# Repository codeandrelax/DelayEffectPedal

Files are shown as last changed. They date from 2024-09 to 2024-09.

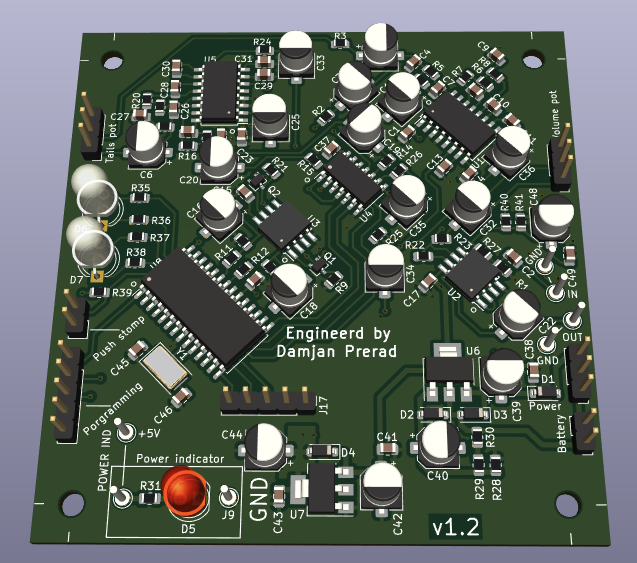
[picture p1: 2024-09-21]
PCB_render.png

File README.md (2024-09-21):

# The Time Manipulator

<p align="center">
  3D render
  Block diagram
</p>

This repository contains schematic, design files and firmware for digital delay guitar effect pedal based on PT2399.
Effect pedal was inspired by [_The Time Manipulator_](https://www.electrosmash.com/time-manipulator) effect pedal.

Electro Smash's pedal is built using popular Arduino ATMEGA328P-PU chip. 
Solution found in this repositroy doesn't use the same microcontroller. It uses PIC16F72.

Board is designed using surface mounted components (SMD).

Aditionaly, I have written on effect pedal design, it can be found in the repository [Analogna Efekt Pedala](./Analogna%20Efekt%20Pedala.pdf) (it's in Serbian)

## First version of the board

<table>
  <tr>
    <td></td>
    <td></td>
    <td></td>
  </tr>
  <tr>
    <td></td>
    <td></td>
    <td></td>
  </tr>
</table>

Firmware and PCB design of PT2399 IC based digital delay  effect guitar pedal

## Development diagram

DevelopmentDiagram

## Render images







## Block diagram



## Schematics
[Schematics](PT2399_DigitalEffectPedal.pdf) PDF can be found in the repository. 



## Layout

Board dimensions are 75 mm by 78 mm.
Board layout is done as 4 layer board.



### Front Cu layer:


### In1. Cu layer:


### In2. Cu layer:
This layer has two power planes. Bigger one is for 5V supply, and the smaller one is for 9V supply.


### Back Cu layer:


## Firmawrae

## Tools

Tool used for schematics drwaing and pcb layout is [KiCad](https://www.kicad.org/), version 7.0.7

Tools used to draw block image is [ExcaliDraw](https://excalidraw.com/).

## TO DO

- Encoder board

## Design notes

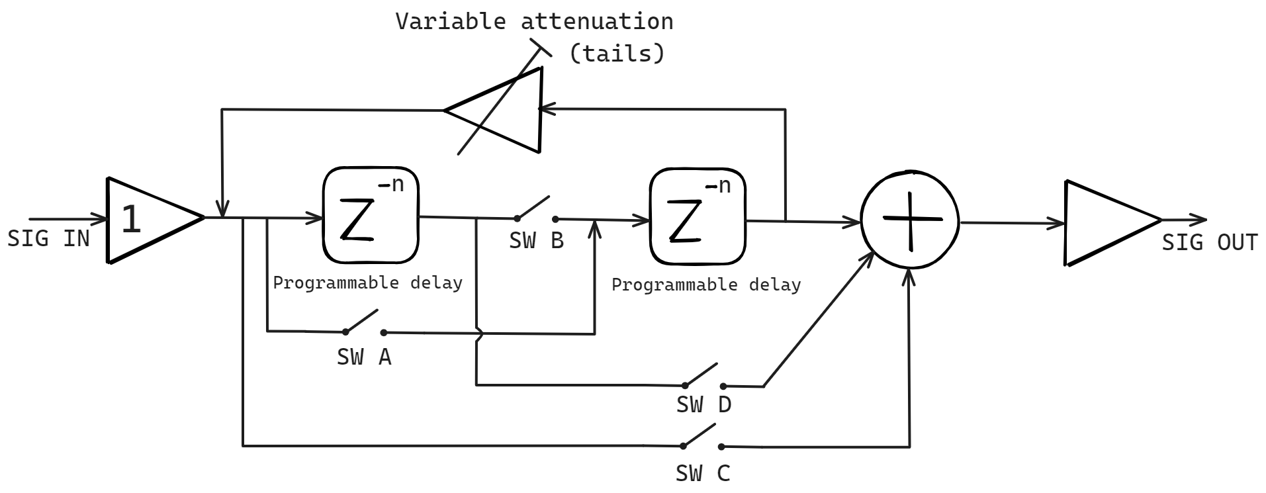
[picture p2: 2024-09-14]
TimeManipulator_blockDiagram.png

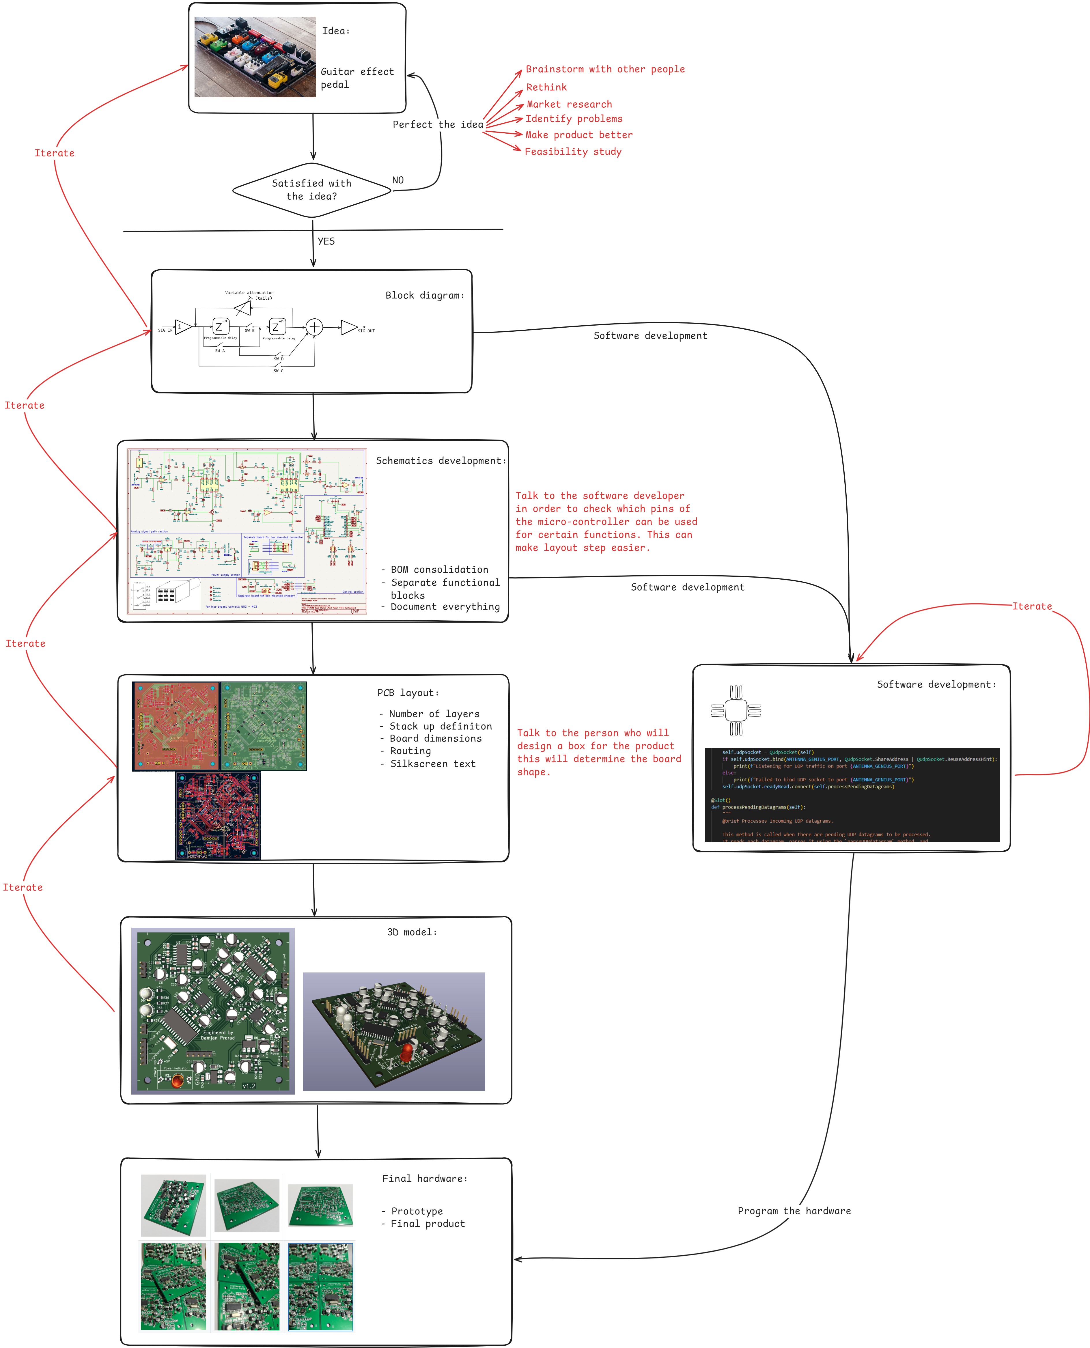
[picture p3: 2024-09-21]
DevelopmentDiagram.png

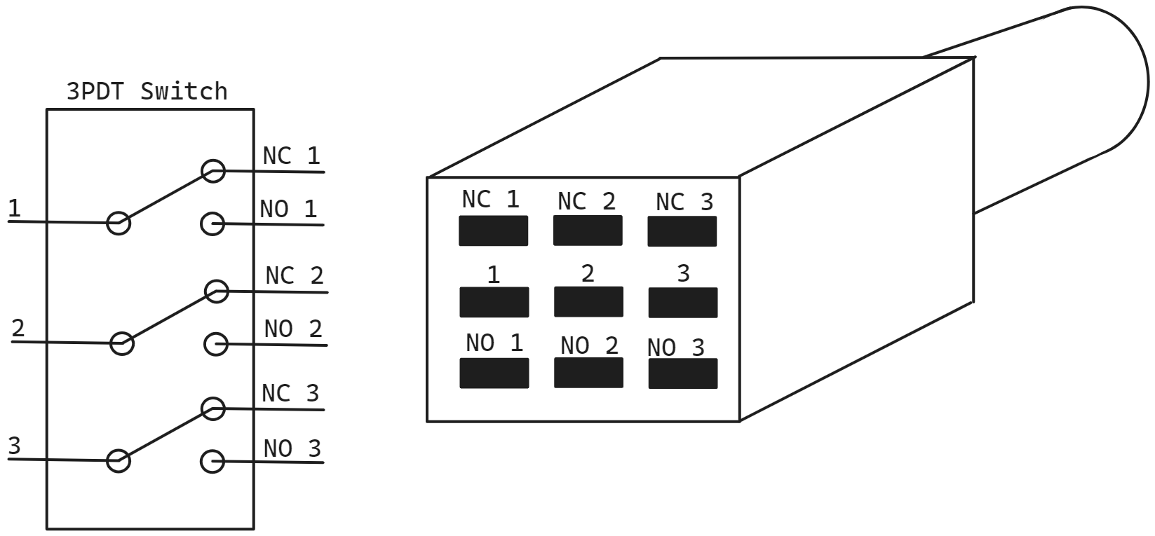
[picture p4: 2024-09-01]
3PDT_switch.png

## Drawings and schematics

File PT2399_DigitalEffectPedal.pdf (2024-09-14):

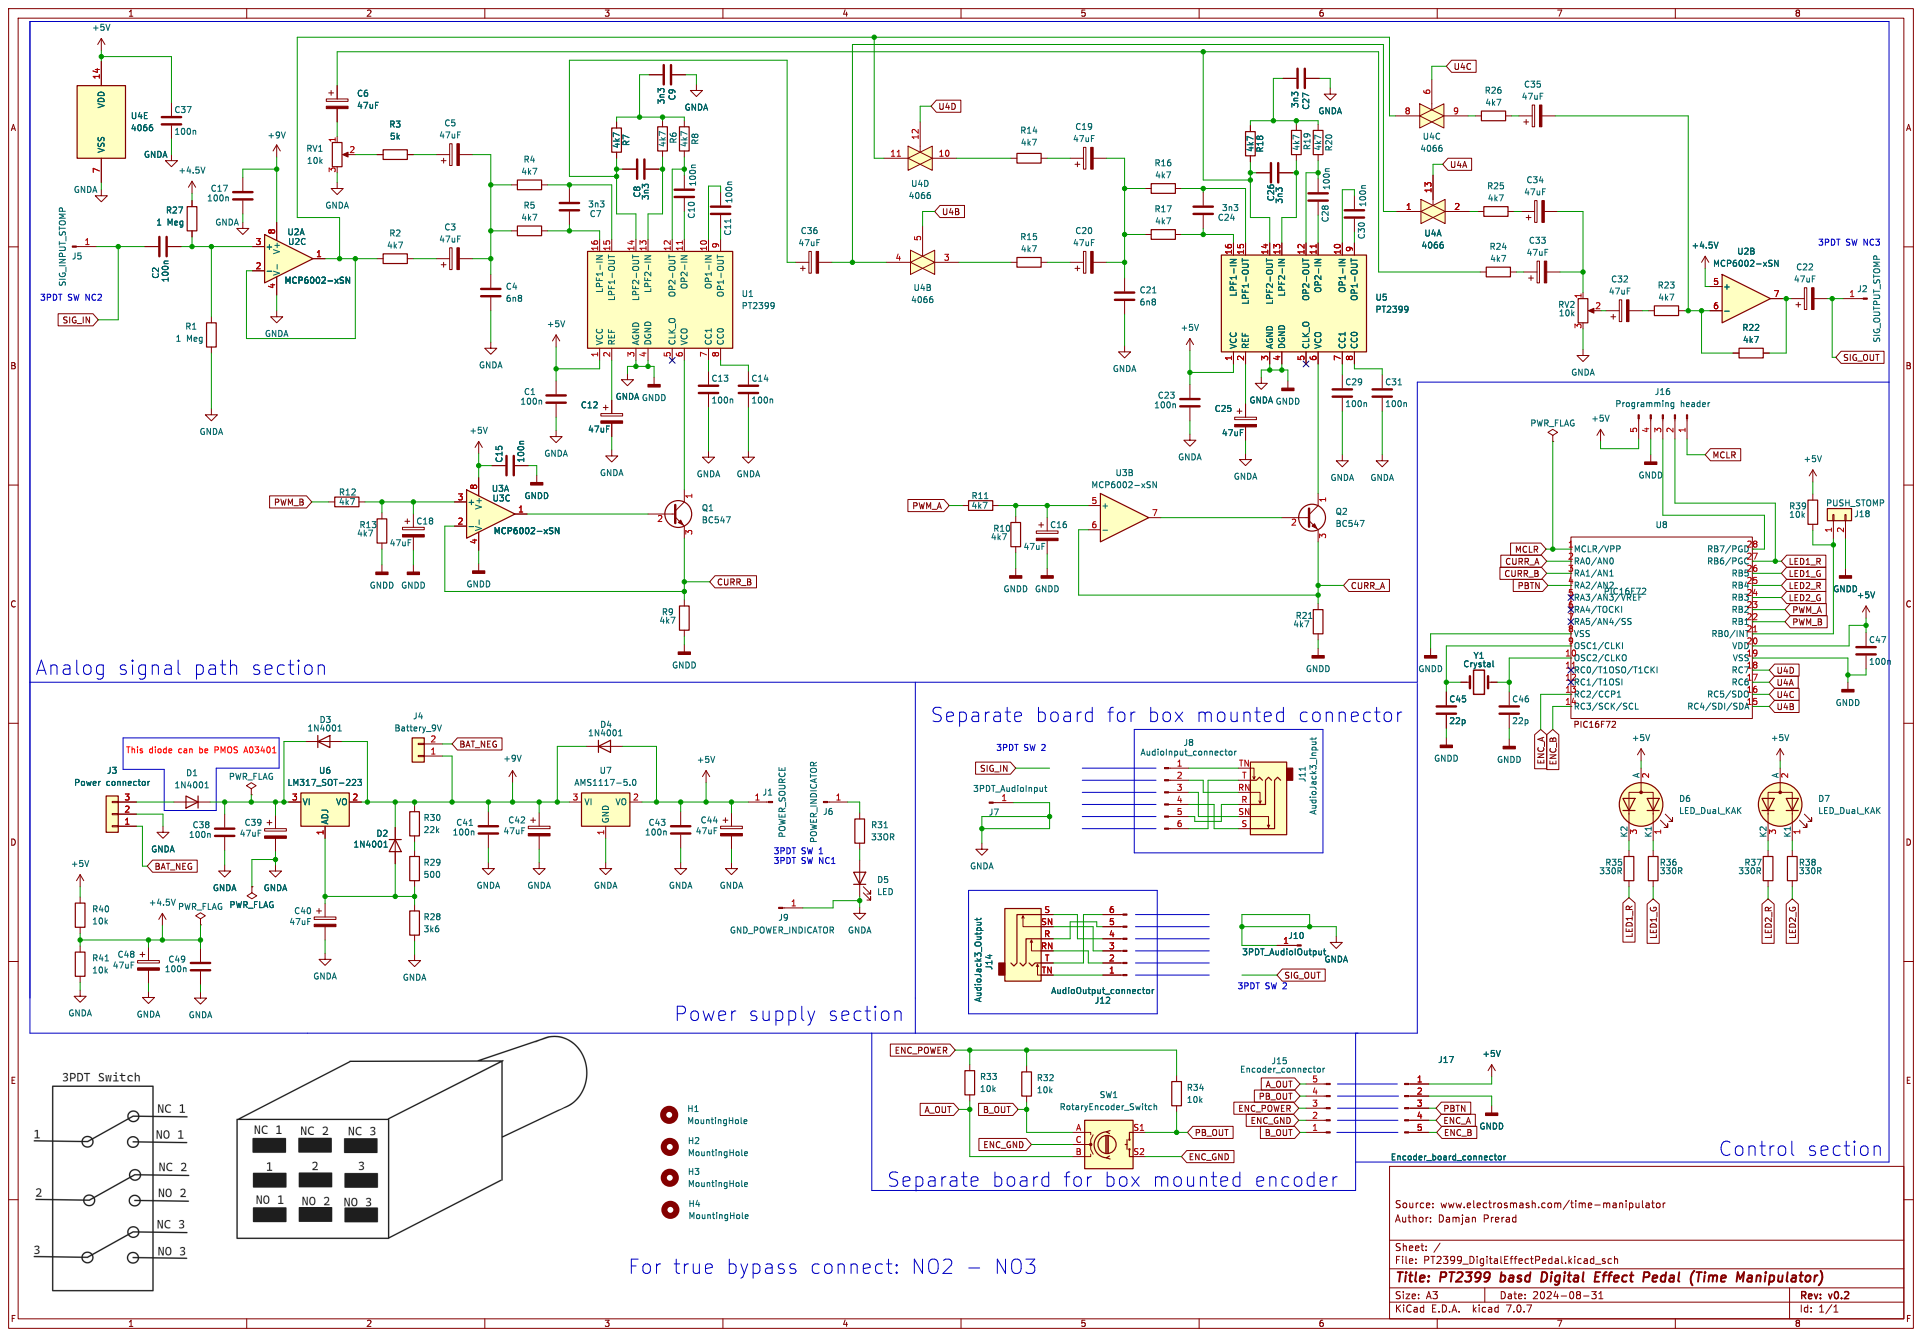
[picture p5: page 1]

1 OP1-IN 10 OP2-IN 11 OP2-OUT 12 LPF2-IN 13 LPF2-OUT 14 LPF1-OUT 15 LPF1-IN 16 REF

Analog signal path section

This diode can be PMOS A03401

3PDT SW NC1 Power supply section

Separate board for box mounted encoder

For true bypass connect: NO2 - NO3

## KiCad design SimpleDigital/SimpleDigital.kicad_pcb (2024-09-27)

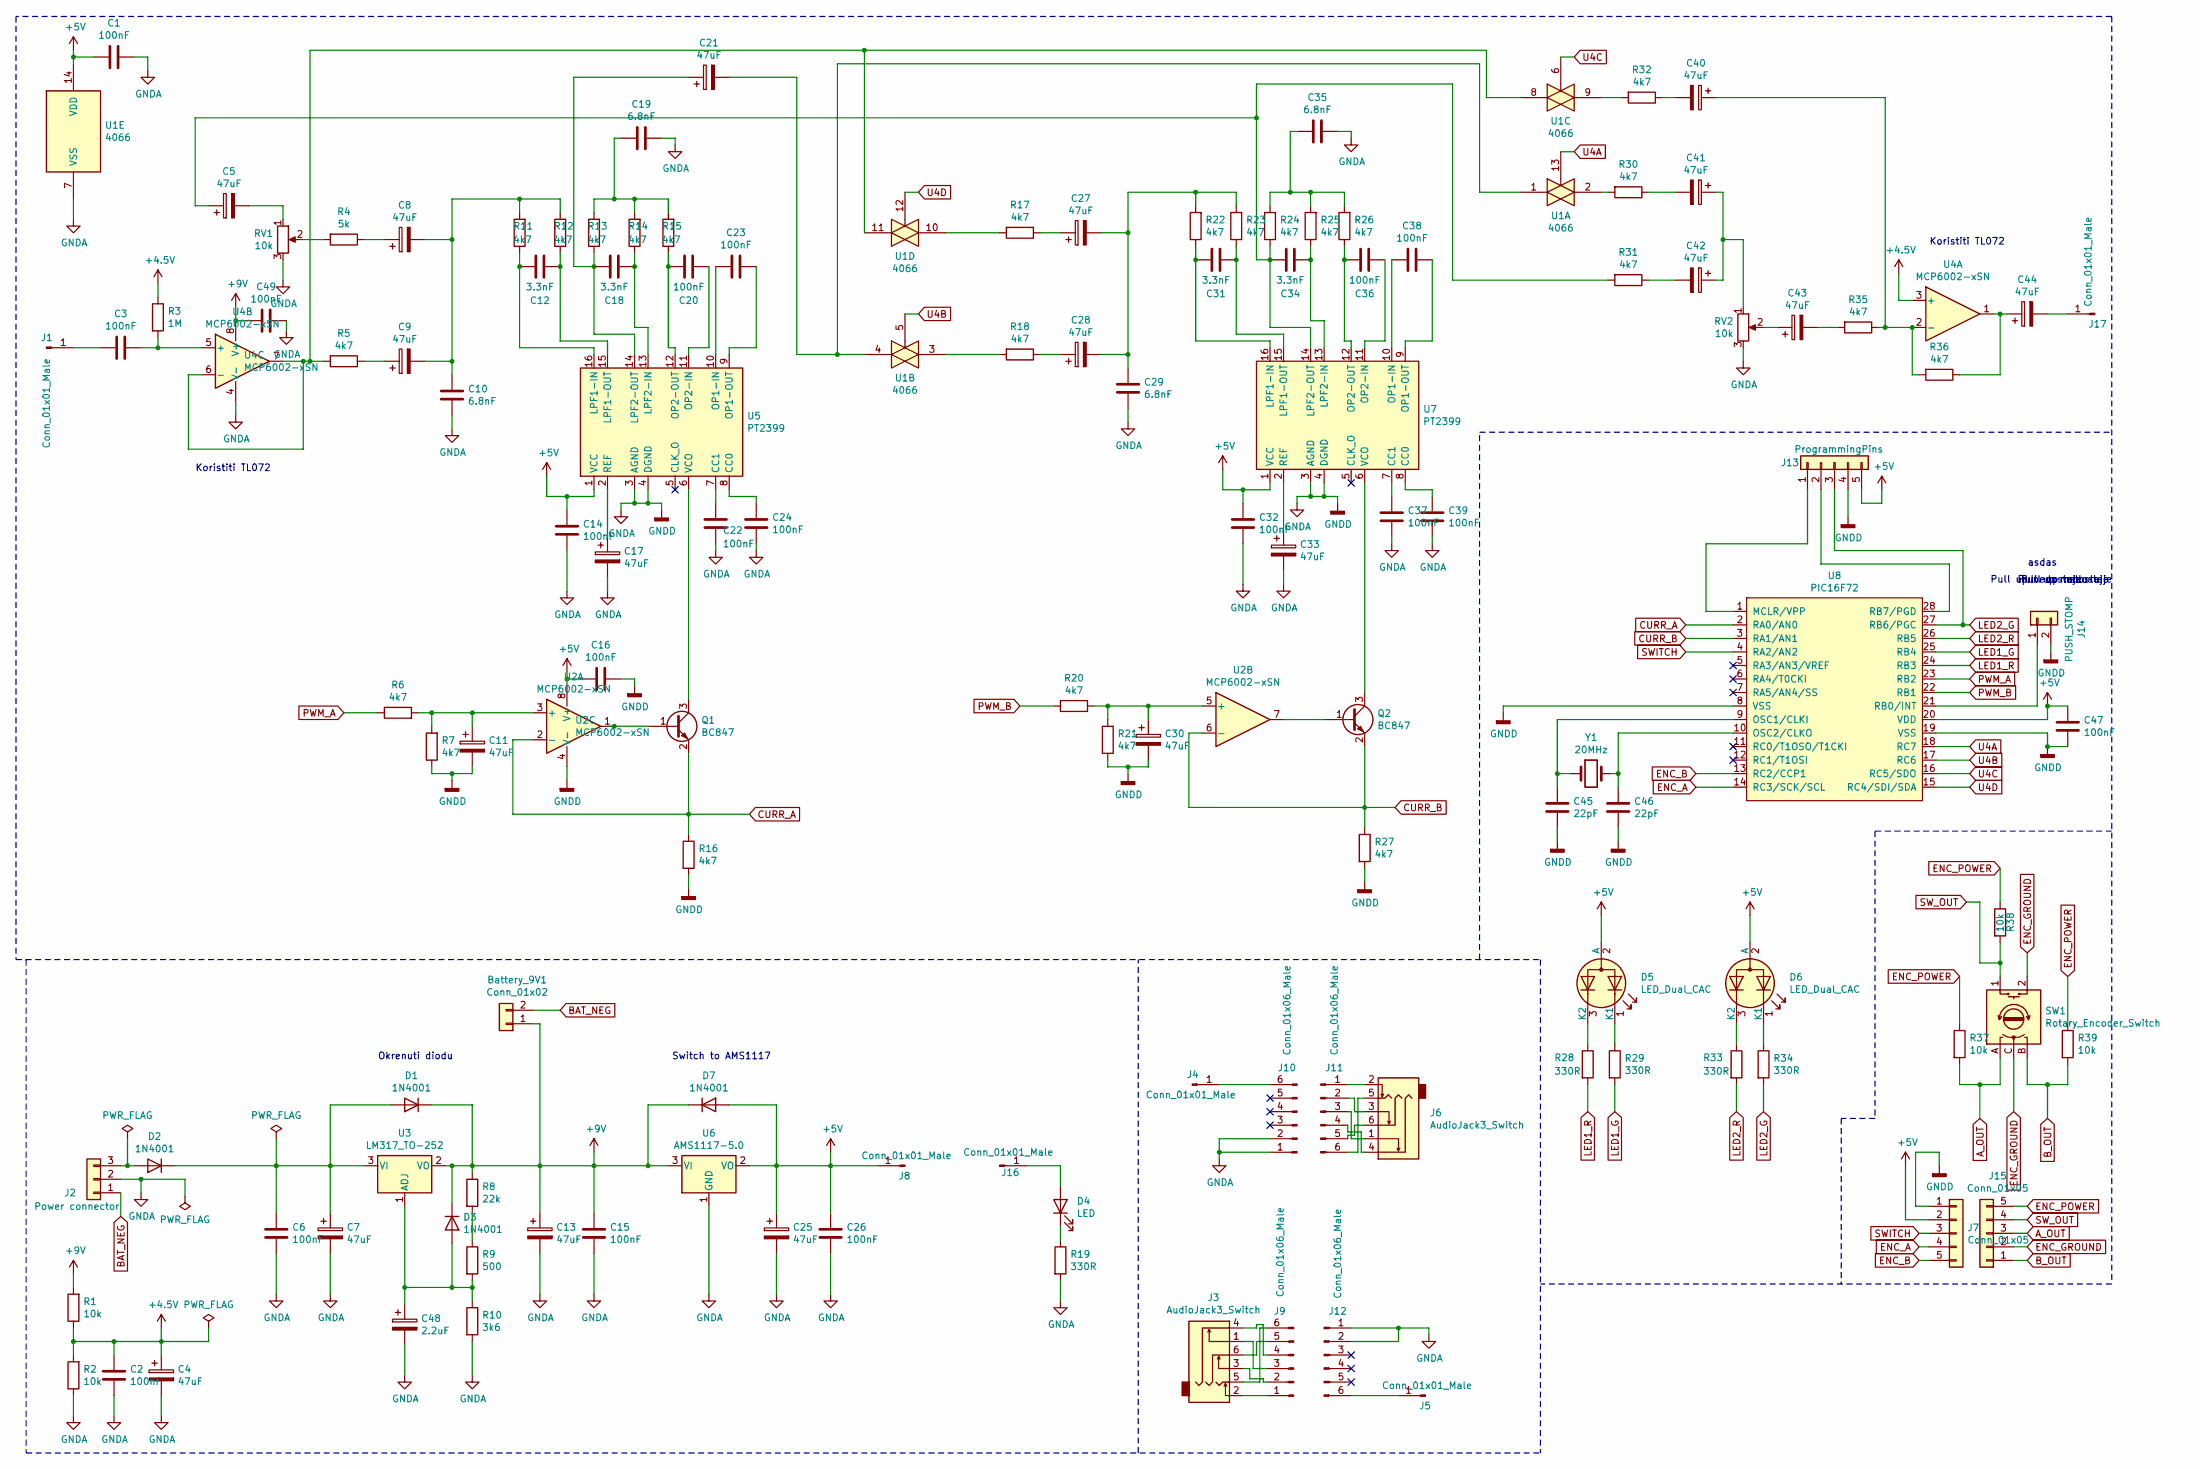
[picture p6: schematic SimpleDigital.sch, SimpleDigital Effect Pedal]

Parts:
Battery_9V1: Conn_01x02; Pin_Header_Straight_1x02_Pitch2.54mm
C1, C2, C3, C6, C14, C15, C16, C20, C22, C23, C24, C26, C32, C36, C37, C38, C39, C47, C49: 100nF; 0805
C4, C5, C7, C8, C9, C11, C13, C17, C21, C25, C27, C28, C30, C33, C40, C41, C42, C43, C44: 47uF; CP_Elec_5x5.3
C10, C19, C29, C35: 6.8nF; 0805
C12, C18, C31, C34: 3.3nF; 0805
C45, C46: 22pF; 0805
C48: 2.2uF; 0805
D1, D2, D3, D7: 1N4001; DO-214AC
D4: LED; LED_D5.0mm
D5, D6: LED_Dual_CAC; LED_D8.0mm-3
J1, J4, J5, J8, J16, J17: Conn_01x01_Male; Pin_d1.4mm_L8.5mm_W2.8mm_FlatFork
J2: Power connector; Pin_Header_Straight_1x03_Pitch2.54mm
J3, J6: AudioJack3_Switch; NMJ6HCD2
J7, J15: Conn_01x05; Pin_Header_Straight_1x05_Pitch2.54mm
J9, J10, J11, J12: Conn_01x06_Male; Pin_Header_Straight_1x06_Pitch2.54mm
J13: ProgrammingPins; Pin_Header_Straight_1x05_Pitch2.54mm
J14: PUSH_STOMP; Pin_Header_Straight_1x02_Pitch2.54mm
Q1, Q2: BC847; SOT-23-3
R1, R2, R37, R38, R39: 10k; 0805
R3: 1M; 0805
R4: 5k; 0805
R5, R6, R7, R11, R12, R13, R14, R15, R16, R17, R18, R20, R21, R22, R23, R24, R25, R26, R27, R30, R31, R32, R35, R36: 4k7; 0805
R8: 22k; 0805
R9: 500; 0805
R10: 3k6; 0805
R19, R28, R29, R33, R34: 330R; 0805
RV1, RV2: 10k; Potentiometer_WirePads_Small
SW1: Rotary_Encoder_Switch; Rotary_Encoder_Switched_PEC11R
U1: 4066; SOIC-14_W3.9mm
U2, U4: MCP6002-xSN; SOIC-8_W3.9mm
U3: LM317_TO-252; SOT-223
U5, U7: PT2399; SOIC-16_W3.90mm
U6: AMS1117-5.0; SOT-223
U8: PIC16F72; SOIC-28_W7.5mm
Y1: 20MHz; Crystal_SMD_HC49-SD_HandSoldering

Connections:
+4V: C2.2, C4.1, R1.1, R2.2, R3.1, U4.3 (+)
+5V: C1.2, C14.1, C16.2, C25.1, C26.2, C32.1, C47.2, D5.2 (A), D6.2 (A), D7.A, J7.2, J8.1, J13.5, U1.14 (VDD), U2.8 (V+), U5.1 (VCC), U6.2 (VO), U7.1 (VCC), U8.20 (VDD)
+9V: Battery_9V1.1, C13.1, C15.2, C49.2, D1.K, D3.K, D7.K, R1.2, R8.1, U3.2 (VO), U4.8 (V+), U6.3 (VI)
A_OUT: J15.3, R37.2, SW1.A
BAT_NEG: Battery_9V1.2, J2.1
B_OUT: J15.1, R39.2, SW1.B
CURR_A: Q1.2 (E), R16.1, U2.2 (-), U8.2 (RA0/AN0)
CURR_B: Q2.2 (E), R27.1, U2.6 (-), U8.3 (RA1/AN1)
ENC_A: J7.4, U8.14 (RC3/SCK/SCL)
ENC_B: J7.5, U8.13 (RC2/CCP1)
ENC_GROUND: J15.2, SW1.2 (S2), SW1.C
ENC_POWER: J15.5, R37.1, R38.1, R39.1
GNDA: C1.1, C2.1, C4.2, C6.1, C7.2, C10.2, C11.2, C13.2, C14.2, C15.1, C16.1, C17.2, C19.2, C22.1, C24.1, C25.2, C26.1, C29.2, C30.2, C32.2, C33.2, C35.2, C37.1, C39.1, C45.1, C46.1, C47.1, C48.2, C49.1, J2.2, J7.1, J10.1, J10.2, J12.1, J12.2, J13.4, J14.2, R2.1, R7.1, R10.2, R16.2, R19.2, R21.1, R27.2, RV1.3, RV2.3, U1.7 (VSS), U2.4 (V-), U4.4 (V-), U5.3 (AGND), U5.4 (DGND), U6.1 (GND), U7.3 (AGND), U7.4 (DGND), U8.8 (VSS), U8.19 (VSS)
LED1_G: R29.2, U8.25 (RB4)
LED1_R: R28.2, U8.24 (RB3)
LED2_G: J13.3, R34.2, U8.27 (RB6/PGC)
LED2_R: R33.2, U8.26 (RB5)
unnamed: C3.1, R3.2, U4.5 (+)
unnamed: C3.2, J1.1
unnamed: C5.2, RV1.1
unnamed: C6.2, C7.1, D1.A, D2.K, U3.3 (VI)
unnamed: C8.1, R4.1
unnamed: C9.1, R5.1
unnamed: C8.2, C9.2, C10.1, R11.2, R12.2
unnamed: C11.1, R6.2, R7.2, U2.3 (+)
unnamed: C12.1, R12.1, U5.15 (LPF1-OUT)
unnamed: C12.2, R11.1, U5.16 (LPF1-IN)
unnamed: C17.1, U5.2 (REF)
unnamed: C18.1, R14.1, U5.13 (LPF2-IN)
unnamed: C18.2, C21.1, R13.1, U5.14 (LPF2-OUT)
unnamed: C19.1, R13.2, R14.2, R15.2
unnamed: C20.1, U5.11 (OP2-IN)
unnamed: C20.2, R15.1, U5.12 (OP2-OUT)
unnamed: C21.2, U1.1, U1.4
unnamed: C22.2, U5.7 (CC1)
unnamed: C23.1, U5.9 (OP1-OUT)
unnamed: C23.2, U5.10 (OP1-IN)
unnamed: C24.2, U5.8 (CC0)
unnamed: C27.1, R17.1
unnamed: C27.2, C28.2, C29.1, R22.2, R23.2
unnamed: C28.1, R18.1
unnamed: C30.1, R20.2, R21.2, U2.5 (+)
unnamed: C31.1, R23.1, U7.15 (LPF1-OUT)
unnamed: C31.2, R22.1, U7.16 (LPF1-IN)
unnamed: C33.1, U7.2 (REF)
unnamed: C34.1, R25.1, U7.13 (LPF2-IN)
unnamed: C5.1, C34.2, R24.1, R31.2, U7.14 (LPF2-OUT)
unnamed: C35.1, R24.2, R25.2, R26.2
unnamed: C36.1, U7.11 (OP2-IN)
unnamed: C36.2, R26.1, U7.12 (OP2-OUT)
unnamed: C37.2, U7.7 (CC1)
unnamed: C38.1, U7.9 (OP1-OUT)
unnamed: C38.2, U7.10 (OP1-IN)
unnamed: C39.2, U7.8 (CC0)
unnamed: C40.1, R35.1, R36.2, U4.2 (-)
unnamed: C40.2, R32.1
unnamed: C41.1, C42.1, RV2.1
unnamed: C41.2, R30.1
unnamed: C42.2, R31.1
unnamed: C43.1, RV2.2
unnamed: C43.2, R35.2
unnamed: C44.1, R36.1, U4.1
unnamed: C44.2, J17.1
unnamed: C45.2, U8.9 (OSC1/CLKI), Y1.1
unnamed: C46.2, U8.10 (OSC2/CLKO), Y1.2
unnamed: C48.1, D3.A, R9.2, R10.1, U3.1 (ADJ)
unnamed: D2.A, J2.3
unnamed: D4.1 (K), R19.1
unnamed: D4.2 (A), J16.1
unnamed: D5.1 (K1), R29.1
unnamed: D5.3 (K2), R28.1
unnamed: D6.1 (K1), R34.1
unnamed: D6.3 (K2), R33.1
unnamed: J3.1, J9.3
unnamed: J3.2, J9.1
unnamed: J3.3, J9.2
unnamed: J3.4, J9.4
unnamed: J3.5, J9.6
unnamed: J3.6, J9.5
unnamed: J4.1, J10.6
unnamed: J6.2, J11.1
unnamed: J6.3, J11.2
unnamed: J6.1, J11.3
unnamed: J6.4, J11.4
unnamed: J6.6, J11.5
unnamed: J6.5, J11.6
unnamed: J5.1, J12.6
unnamed: J13.1, U8.1 (MCLR/VPP)
unnamed: J13.2, U8.28 (RB7/PGD)
unnamed: J14.1, U8.21 (RB0/INT)
unnamed: Q1.1 (B), U2.1
unnamed: Q1.3 (C), U5.6 (VCO)
unnamed: Q2.1 (B), U2.7
unnamed: Q2.3 (C), U7.6 (VCO)
unnamed: R4.2, RV1.2
unnamed: R5.2, U1.8, U1.11, U4.6 (-), U4.7
unnamed: R8.2, R9.1
unnamed: R17.2, U1.10
unnamed: R18.2, U1.3
unnamed: R30.2, U1.2
unnamed: R32.2, U1.9
PWM_A: R6.1, U8.23 (RB2)
PWM_B: R20.1, U8.22 (RB1)
SWITCH: J7.3, U8.4 (RA2/AN2)
SW_OUT: J15.4, R38.2, SW1.1 (S1)
U4A: U1.13, U8.18 (RC7)
U4B: U1.5, U8.17 (RC6)
U4C: U1.6, U8.16 (RC5/SDO)
U4D: U1.12, U8.15 (RC4/SDI/SDA)

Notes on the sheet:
Switch to AMS1117
Okrenuti diodu
Pull up nedostaje
asdas
Pull up nedostaje
Koristiti TL072

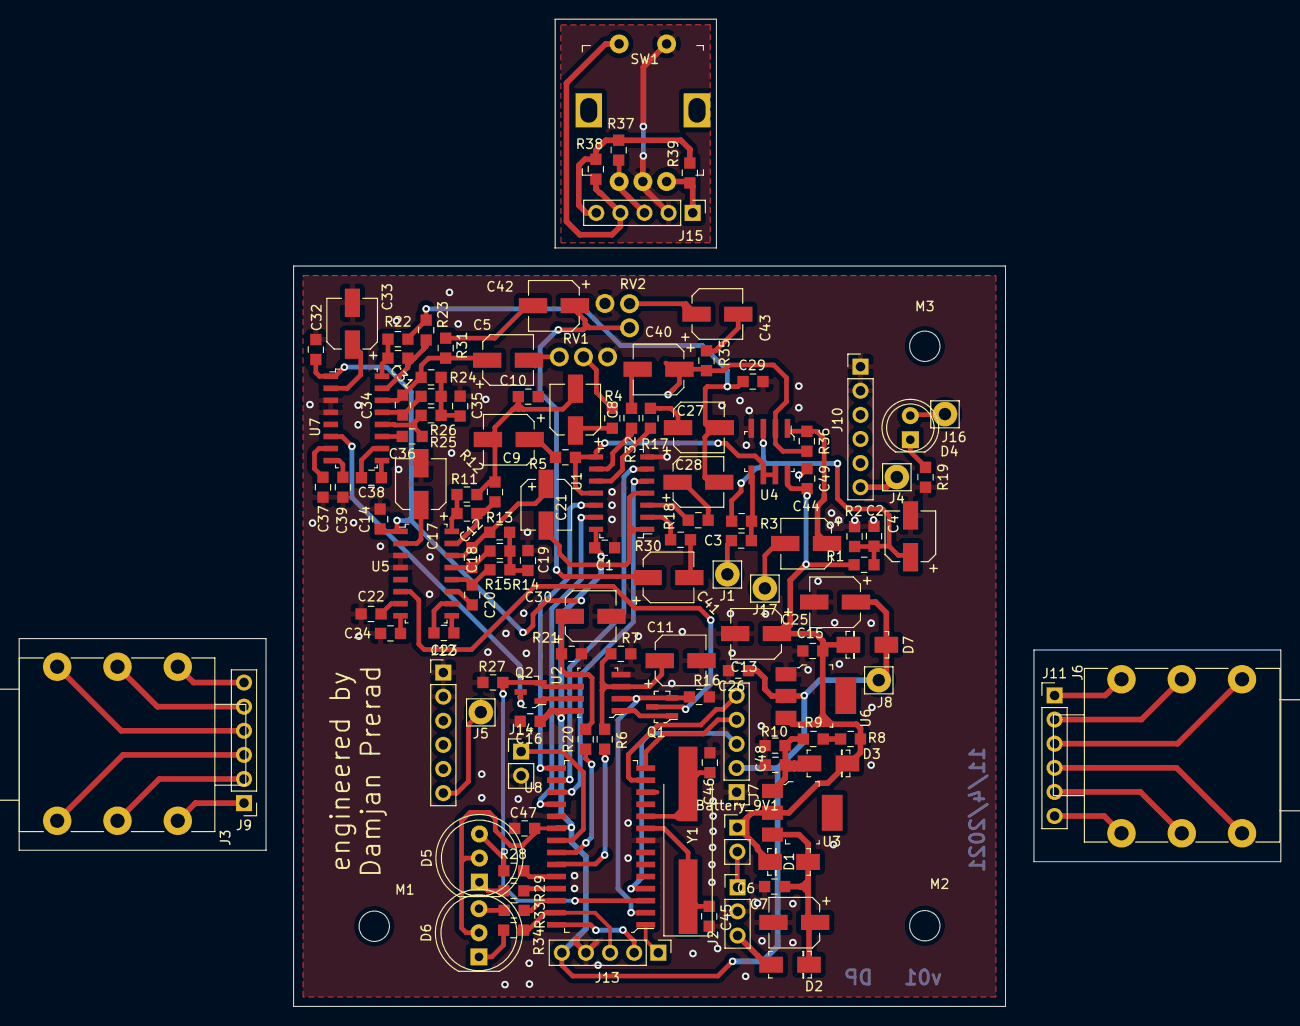
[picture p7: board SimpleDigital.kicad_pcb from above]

Board: 2 copper layers, 75.0 x 78.0 mm, 130 parts (0 on the bottom side), 109 nets.

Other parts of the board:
M1, M2, M3: MountingHole_3.2mm_M3

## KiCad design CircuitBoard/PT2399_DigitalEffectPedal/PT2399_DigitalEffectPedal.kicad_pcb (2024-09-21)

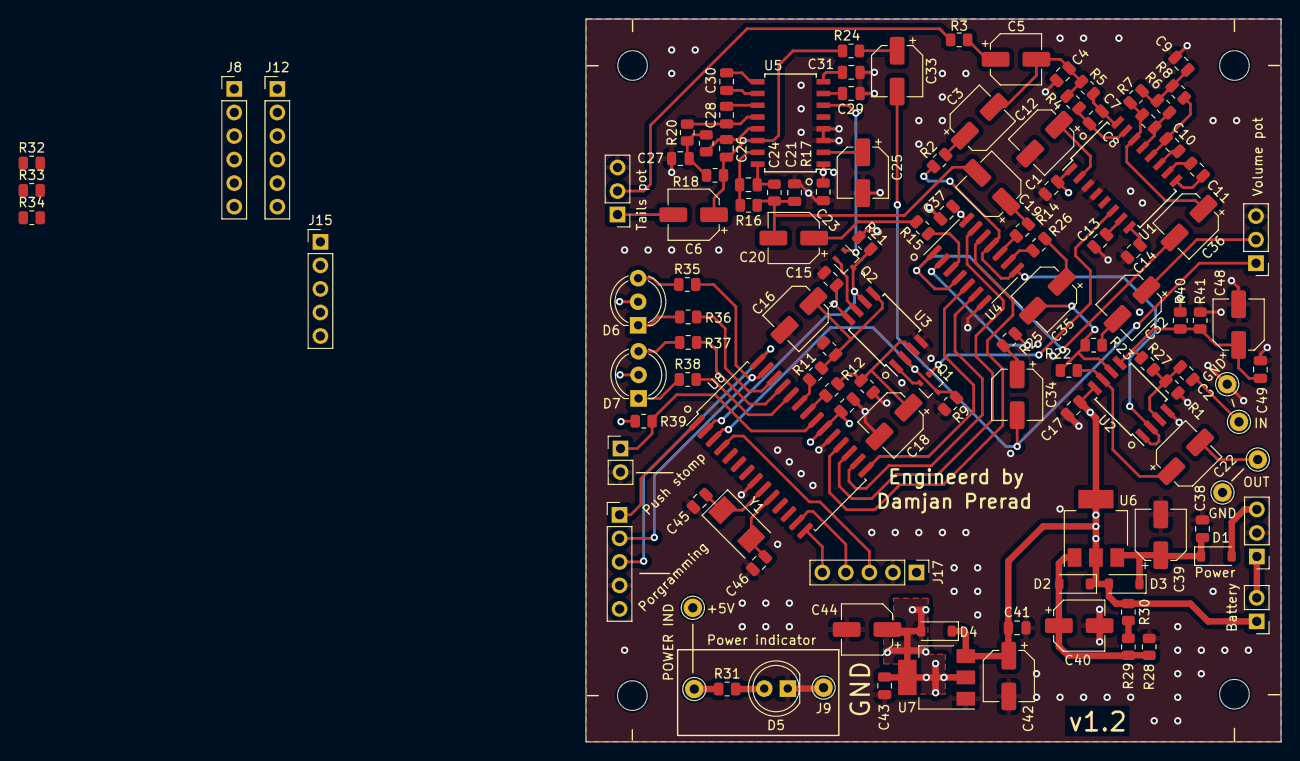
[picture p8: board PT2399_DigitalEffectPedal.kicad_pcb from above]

Board: 4 copper layers, 75.0 x 78.0 mm, 130 parts (1 on the bottom side), 94 nets.

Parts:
 : MountingHole; MountingHole_3.2mm_M3
 #2,  #3,  #4: MountingHole; MountingHole_3.2mm_M3
 #5: POWER_SOURCE; Pin_D1.0mm_L10.0mm
 #6: LOGO
Battery: Battery_9V; PinHeader_1x02_P2.54mm_Vertical
C1, C2, C10, C11, C13, C14, C15, C17, C23, C28, C29, C30, C31, C37, C38, C41, C43, C47, C49: 100n; C_0805_2012Metric
C3, C5, C6, C12, C16, C18, C19, C20, C22, C25, C32, C33, C34, C35, C36, C39, C40, C42, C44, C48: 47uF; CP_Elec_5x5.3
C4, C21: 6n8; C_0805_2012Metric
C7, C8, C9, C24, C26, C27: 3n3; C_0805_2012Metric
C45, C46: 22p; C_0805_2012Metric
D1, D2, D3, D4: 1N4001; D_SOD-123
D5: LED; LED_D5.0mm
D6, D7: LED_Dual_KAK; LED_D5.0mm-3
GND: 3PDT_AudioInput; Pin_D1.0mm_L10.0mm
GND#2: 3PDT_AudioIOutput; Pin_D1.0mm_L10.0mm
IN: SIG_INPUT_STOMP; Pin_D1.0mm_L10.0mm
J8: AudioInput_connector; PinHeader_1x06_P2.54mm_Vertical
J9: GND_POWER_INDICATOR; Pin_D1.0mm_L10.0mm
J12: AudioOutput_connector; PinHeader_1x06_P2.54mm_Vertical
J15: Encoder_connector; PinHeader_1x05_P2.54mm_Vertical
J17: Encoder_board_connector; PinHeader_1x05_P2.54mm_Vertical
OUT: SIG_OUTPUT_STOMP; Pin_D1.0mm_L10.0mm
POWER IND: POWER_INDICATOR; Pin_D1.0mm_L10.0mm
Porgramming: Programming header; PinHeader_1x05_P2.54mm_Vertical
Power: Power connector; PinHeader_1x03_P2.54mm_Vertical
Push stomp: PUSH_STOMP; PinHeader_1x02_P2.54mm_Vertical
Q1, Q2: BC547; SOT-323_SC-70
R1, R27: 1 Meg; R_0805_2012Metric
R2, R4, R5, R6, R7, R8, R9, R10, R11, R12, R13, R14, R15, R16, R17, R18, R19, R20, R21, R22, R23, R24, R25, R26: 4k7; R_0805_2012Metric
R3: 5k; R_0805_2012Metric
R28: 3k6; R_0805_2012Metric
R29: 500; R_0805_2012Metric
R30: 22k; R_0805_2012Metric
R31: 33OR; R_0805_2012Metric
R32, R33, R34, R39, R40, R41: 10k; R_0805_2012Metric
R35, R36, R37, R38: 330R; R_0805_2012Metric
Tails pot: 10k; PinHeader_1x03_P2.54mm_Vertical
U1, U5: PT2399; SOIC-16W_5.3x10.2mm_P1.27mm
U2, U3: MCP6002-xSN; SOIC-8W_5.3x5.3mm_P1.27mm
U4: 4066; SOIC-14_3.9x8.7mm_P1.27mm
U6: LM317_SOT-223; SOT-223-3_TabPin2
U7: AMS1117-5.0; SOT-223-3_TabPin2
U8: PIC16F72; SOIC-28W_7.5x17.9mm_P1.27mm
Volume pot: 10k; PinHeader_1x03_P2.54mm_Vertical
Y1: Crystal; Crystal_SMD_0603-2Pin_6.0x3.5mm

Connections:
+4.5V: C48.1, C49.1, R27.1, R40.2, R41.1, U2.5 (+)
+5V: #5.1, C1.1, C15.1, C23.1, C37.1, C43.1, C44.1, C47.1, D4.2 (A), D6.2 (A), D7.2 (A), J17.1, Porgramming.5, R39.1, R40.1, U1.1 (VCC), U3.8 (V+), U4.14 (VDD), U5.1 (VCC), U7.2 (VO), U8.20 (VDD)
+9V: Battery.1, C17.1, C41.1, C42.1, D2.1 (K), D3.2 (A), D4.1 (K), R30.1, U2.8 (V+), U6.2 (VO), U7.3 (VI)
A_OUT: J15.5, R33.2
BAT_NEG: Battery.2, Power.1
B_OUT: J15.1, R32.2
CURR_A: Q2.3 (E), R21.1, U3.6 (-), U8.2 (RA0/AN0)
CURR_B: Q1.3 (E), R9.1, U3.2 (-), U8.3 (RA1/AN1)
ENC_A: J17.4, U8.13 (RC2/CCP1)
ENC_B: J17.5, U8.14 (RC3/SCK/SCL)
ENC_POWER: J15.3, R32.1, R33.1, R34.1
GNDA: C1.2, C4.2, C9.1, C12.2, C13.2, C14.2, C15.2, C16.2, C17.2, C18.2, C21.2, C23.2, C25.2, C27.1, C29.2, C31.2, C37.2, C38.2, C39.2, C40.2, C41.2, C42.2, C43.2, C44.2, C45.2, C46.2, C47.2, C48.2, C49.2, D5.1 (K), GND.1, GND#2.1, J9.1, J17.2, Porgramming.4, Power.2, Push stomp.2, R1.2, R9.2, R10.2, R13.2, R21.2, R28.2, R41.2, Tails pot.3, U1.3 (AGND), U1.4 (DGND), U2.4 (V-), U3.4 (V-), U4.7 (VSS), U5.3 (AGND), U5.4 (DGND), U7.1 (GND), U8.8 (VSS), U8.19 (VSS), Volume pot.3
LED1_G: R36.2, U8.26 (RB5)
LED1_R: Porgramming.2, R35.2, U8.27 (RB6/PGC)
LED2_G: R38.2, U8.24 (RB3)
LED2_R: R37.2, U8.25 (RB4)
MCLR: Porgramming.1, U8.1 (MCLR/VPP)
unnamed: C3.1, R2.2
unnamed: C3.2, C4.1, C5.2, R4.1, R5.1
unnamed: C5.1, R3.2
unnamed: C6.2, Tails pot.1
unnamed: C9.2, R6.1, R7.1, R8.1
unnamed: C19.1, R14.2
unnamed: C19.2, C20.2, C21.1, R16.1, R17.1
unnamed: C20.1, R15.2
unnamed: C22.1, R22.2, U2.7
unnamed: C27.2, R18.1, R19.1, R20.1
unnamed: C32.1, Volume pot.2
unnamed: C32.2, R23.1
unnamed: C33.1, R24.2
unnamed: C33.2, C34.2, Volume pot.1
unnamed: C34.1, R25.2
unnamed: C35.1, R26.2
unnamed: C36.2, U4.1, U4.4
unnamed: D1.2 (A), Power.3
unnamed: C38.1, C39.1, D1.1 (K), D3.1 (K), U6.3 (VI)
unnamed: C40.1, D2.2 (A), R28.1, R29.2, U6.1 (ADJ)
unnamed: D5.2 (A), R31.2
unnamed: D6.1 (K1), R36.1
unnamed: D6.3 (K2), R35.1
unnamed: D7.1 (K1), R38.1
unnamed: D7.3 (K2), R37.1
unnamed: POWER IND.1, R31.1
unnamed: Porgramming.3, U8.28 (RB7/PGD)
unnamed: Push stomp.1, R39.2, U8.21 (RB0/INT)
unnamed: Q1.2 (B), U3.1
unnamed: Q1.1 (C), U1.6 (VCO)
unnamed: Q2.2 (B), U3.7
unnamed: Q2.1 (C), U5.6 (VCO)
unnamed: R3.1, Tails pot.2
unnamed: R14.1, U4.10
unnamed: R15.1, U4.3
unnamed: R25.1, U4.2
unnamed: R26.1, U4.9
unnamed: R29.1, R30.2
unnamed: C14.1, U1.8 (CC0)
unnamed: C13.1, U1.7 (CC1)
unnamed: C7.1, R5.2, U1.16 (LPF1-IN)
unnamed: C7.2, R4.2, U1.15 (LPF1-OUT)
unnamed: C8.2, R6.2, U1.13 (LPF2-IN)
unnamed: C8.1, C36.1, R7.2, U1.14 (LPF2-OUT)
unnamed: C11.2, U1.10 (OP1-IN)
unnamed: C11.1, U1.9 (OP1-OUT)
unnamed: C10.1, U1.11 (OP2-IN)
unnamed: C10.2, R8.2, U1.12 (OP2-OUT)
unnamed: C12.1, U1.2 (REF)
unnamed: C2.2, R1.1, R27.2, U2.3 (+)
unnamed: R2.1, U2.1, U2.2 (-), U4.8, U4.11
unnamed: C35.2, R22.1, R23.2, U2.6 (-)
unnamed: C18.1, R12.1, R13.1, U3.3 (+)
unnamed: C16.1, R10.1, R11.1, U3.5 (+)
unnamed: C31.1, U5.8 (CC0)
unnamed: C29.1, U5.7 (CC1)
unnamed: C24.1, R17.2, U5.16 (LPF1-IN)
unnamed: C24.2, R16.2, U5.15 (LPF1-OUT)
unnamed: C26.2, R19.2, U5.13 (LPF2-IN)
unnamed: C6.1, C26.1, R18.2, R24.1, U5.14 (LPF2-OUT)
unnamed: C30.2, U5.10 (OP1-IN)
unnamed: C30.1, U5.9 (OP1-OUT)
unnamed: C28.1, U5.11 (OP2-IN)
unnamed: C28.2, R20.2, U5.12 (OP2-OUT)
unnamed: C25.1, U5.2 (REF)
unnamed: C45.1, U8.9 (OSC1/CLKI), Y1.1
unnamed: C46.1, U8.10 (OSC2/CLKO), Y1.2
PBTN: J17.3, U8.4 (RA2/AN2)
PB_OUT: J15.4, R34.2
PWM_A: R11.2, U8.23 (RB2)
PWM_B: R12.2, U8.22 (RB1)
SIG_IN: C2.1, IN.1
SIG_OUT: C22.2, OUT.1
U4A: U4.13, U8.17 (RC6)
U4B: U4.5, U8.15 (RC4/SDI/SDA)
U4C: U4.6, U8.16 (RC5/SDO)
U4D: U4.12, U8.18 (RC7)

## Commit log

2024-09-01 Schematics done, pcb layout needs to be done as well as firmware for control section
    [PT2399_DigitalEffectPedal.kicad_pcb, PT2399_DigitalEffectPedal.kicad_sch]
2024-09-10 PCB layout
    [PT2399_DigitalEffectPedal.kicad_pcb, PT2399_DigitalEffectPedal.kicad_sch]
2024-09-10 Layout PCB
    [PT2399_DigitalEffectPedal.kicad_pcb]
2024-09-14 PCB layout - main part
    [PT2399_DigitalEffectPedal.kicad_pcb, PT2399_DigitalEffectPedal.kicad_sch]
2024-09-14 Some warningss and errors fixed, added silk screen block diagram
    [PT2399_DigitalEffectPedal.kicad_pcb]
2024-09-14 Minor estetic changes to board layout
    [PT2399_DigitalEffectPedal.kicad_pcb]
2024-09-14 Minor estetic changes
    [PT2399_DigitalEffectPedal.kicad_pcb]
2024-09-21 Added GND vias to connect power planes
    [PT2399_DigitalEffectPedal.kicad_pcb, PT2399_DigitalEffectPedal.kicad_sch]
2024-09-27 Added earlier version, from couple of years ago
    [SimpleDigital-B_Cu.gbr, SimpleDigital-B_Mask.gbr, SimpleDigital-B_Paste.gbr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]
